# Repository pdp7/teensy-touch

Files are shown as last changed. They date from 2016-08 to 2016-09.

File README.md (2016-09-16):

# Teensy LC cap touch demo
Capactive touch button demo board for Teensy LC with Adafruit 128x64 OLED (SPI)

## OSH Park Shared Project:
* **[Teensy LC cap touch demo](https://oshpark.com/projects/ro7ypcxO)**
   * This is what was ordered and tested
   * File: [teensy-touch.kicad_pcb](https://github.com/pdp7/teensy-touch/blob/5fb2f44a5e37c01898689bddd4195240e6bf3efe/hardware/teensy-touch.kicad_pcb)
   * Commit: [5fb2f44 *connect GND pin for OLED to GND plane*
](https://github.com/pdp7/teensy-touch/commit/5fb2f44a5e37c01898689bddd4195240e6bf3efe)

## Bill of Materials:
* [Monochrome 0.96" 128x64 OLED graphic display](https://www.adafruit.com/product/326)
* [Teensy LC, OSH Park edition](http://store.oshpark.com/products/teensy-lc)

## Videos
* [Short demo](https://www.youtube.com/watch?v=SUqngf3_1D0)
* [Full demo](https://youtu.be/iRWQk5bGx8w)

## Photos
* [Google+ gallery](https://plus.google.com/photos/+DrewFustini/albums/6318204370050037249)
* [images directory](images)

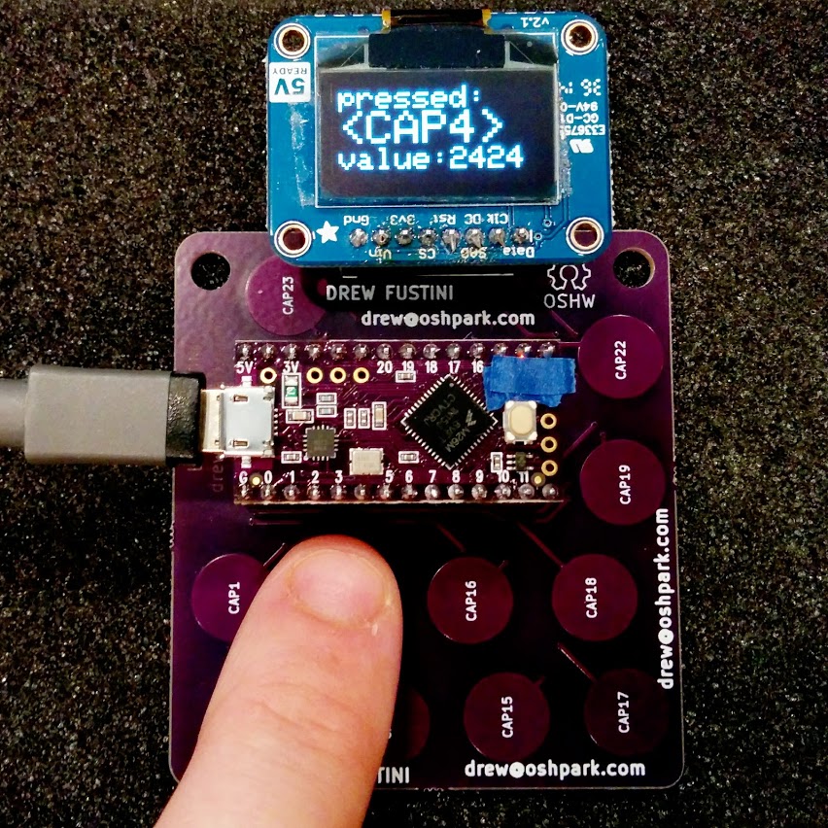
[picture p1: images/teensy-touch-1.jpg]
Photo of teensy-touch board


## License
This project released under the CERN Open Hardware v1.2 License

**Note:** `teensy-touch.ino` contains code based on:

* [Capacitive sensors with the Teensy 3.0](http://njhurst.com/blog/01356576041)
* [SSD1306 display code based on example by Paul Stoffregen](https://www.pjrc.com/teensy/td_libs_SSD1306.html)

## Contact
* Drew Fustini &lt;drew@oshpark.com&gt;

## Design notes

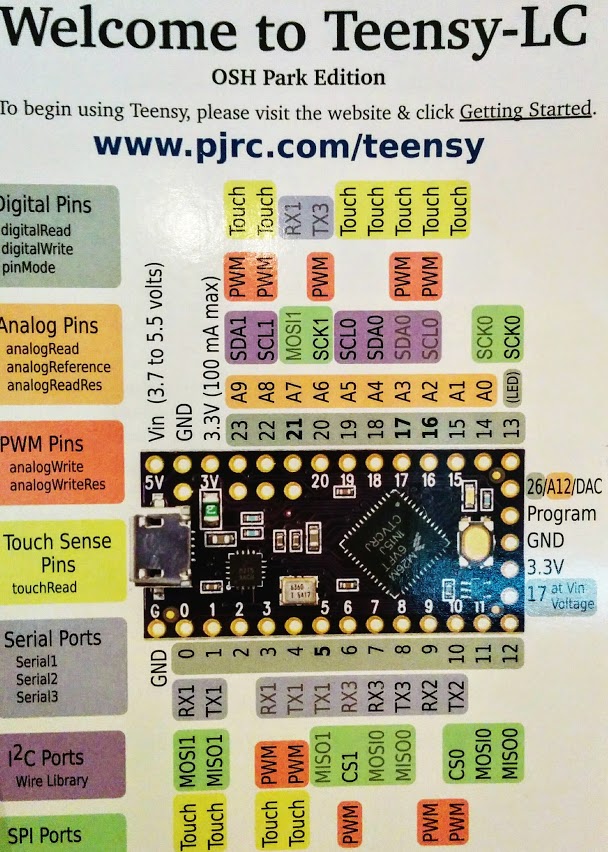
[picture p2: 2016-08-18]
images/teensy-touch-2.jpg

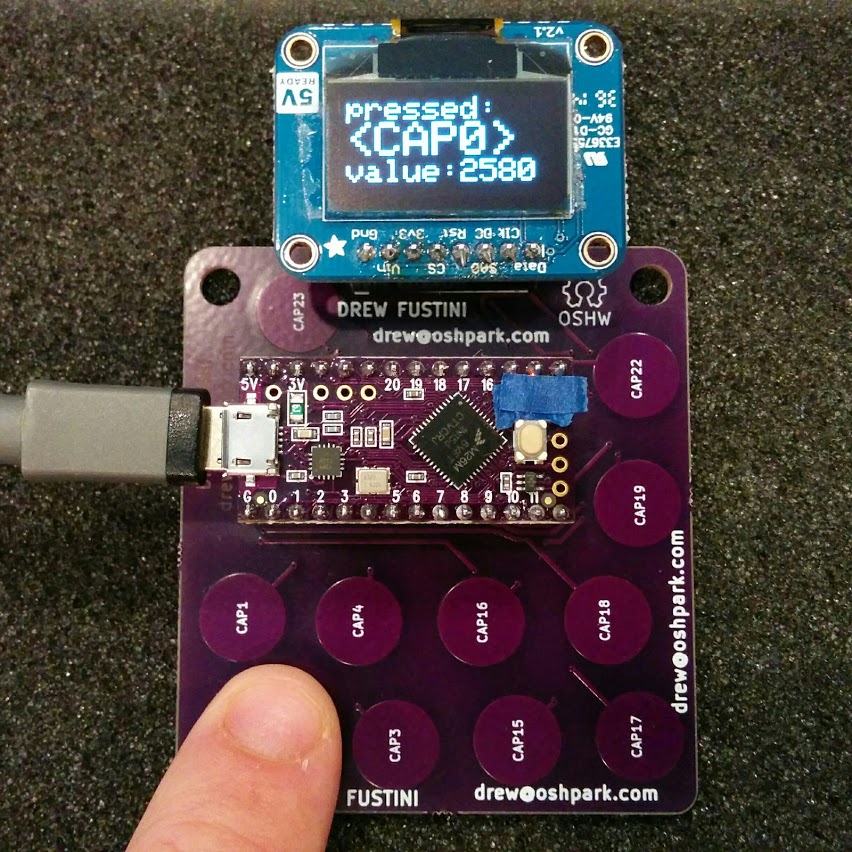
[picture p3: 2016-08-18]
images/teensy-touch-3.jpg

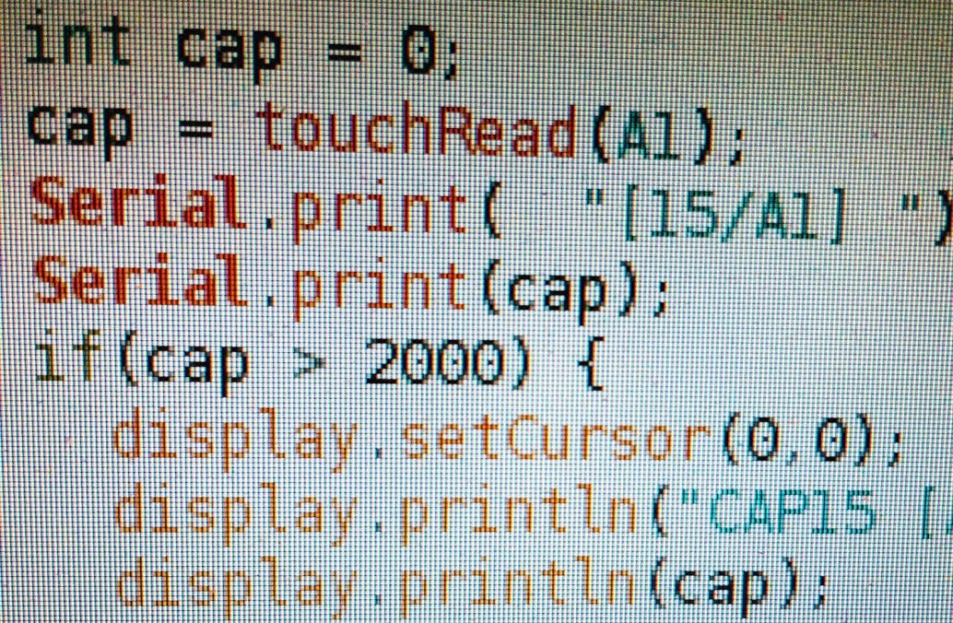
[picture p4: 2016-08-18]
images/teensy-touch-4.jpg

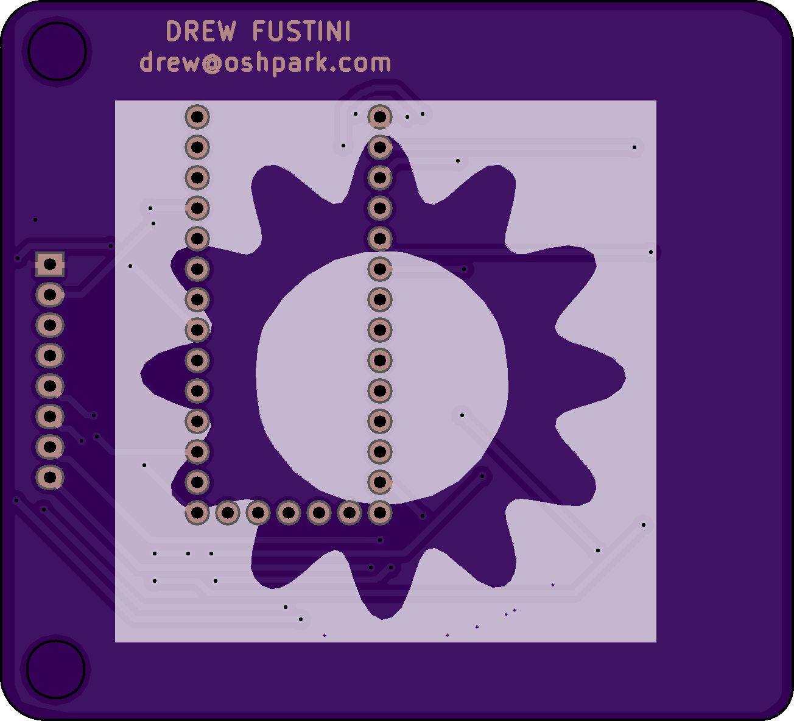
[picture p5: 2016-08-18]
images/back-pcb-preview.png

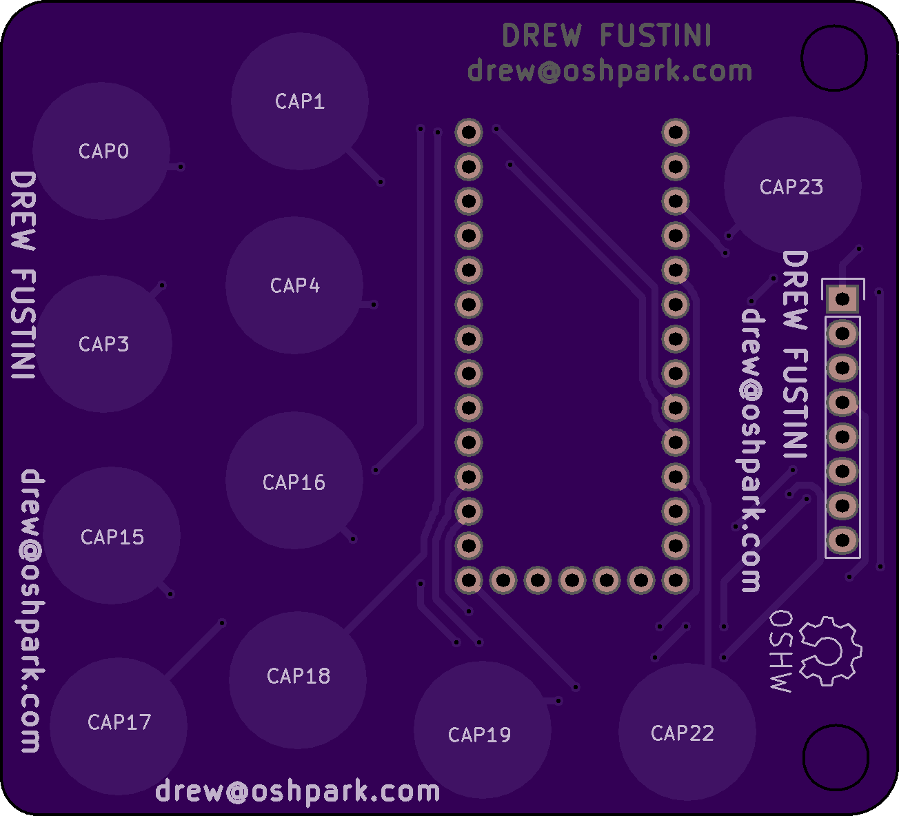
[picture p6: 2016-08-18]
images/front-pcb-preview.png

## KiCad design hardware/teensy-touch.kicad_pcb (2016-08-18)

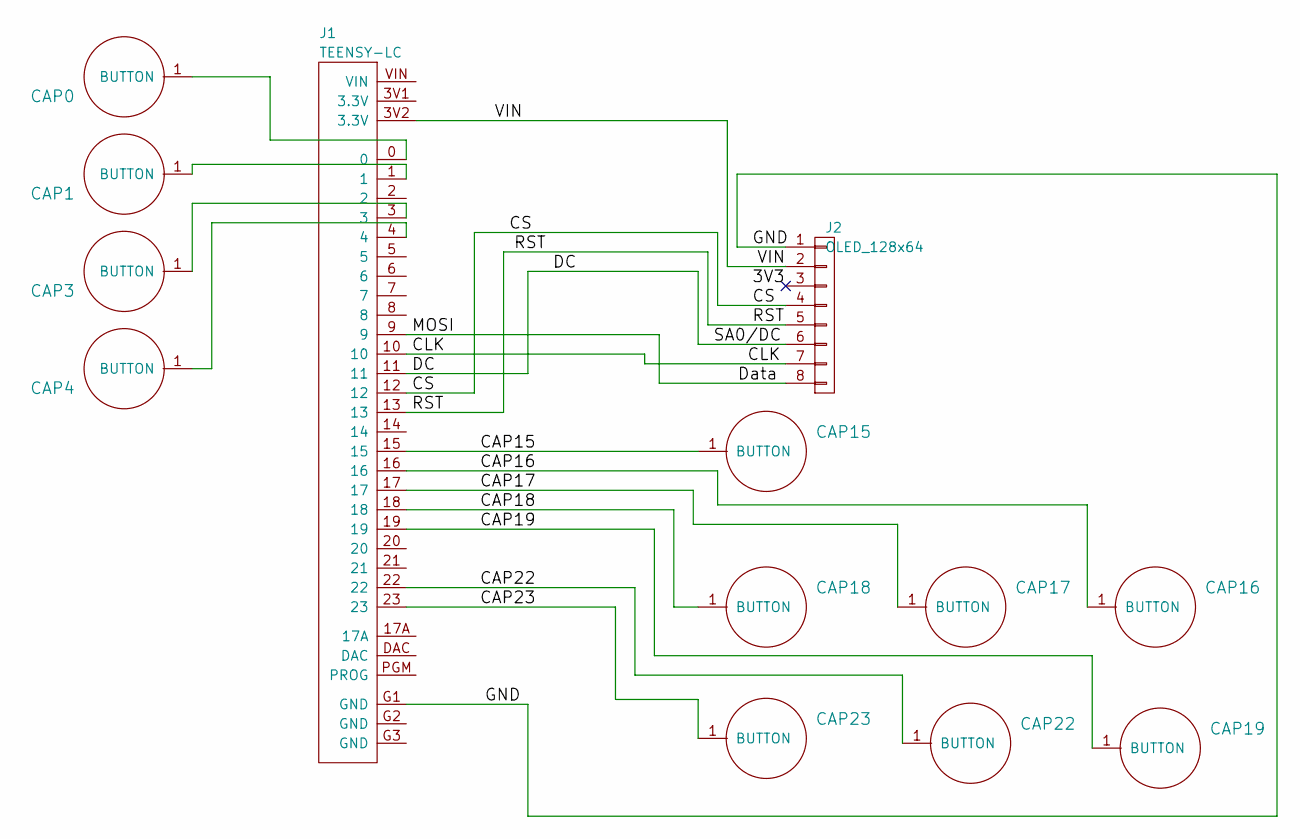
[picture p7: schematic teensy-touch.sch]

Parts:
CAP0, CAP1, CAP3, CAP4, CAP15, CAP16, CAP17, CAP18, CAP19, CAP22, CAP23: CAPSENSE_CIRCLE; CAPSENSE_CIRCLE_D10
J1: TEENSY-LC
J2: OLED_128x64; Pin_Header_Straight_1x08

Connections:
/CAP15: CAP15.1, J1.15
/CAP16: CAP16.1, J1.16
/CAP17: CAP17.1, J1.17
/CAP18: CAP18.1, J1.18
/CAP19: CAP19.1, J1.19
/CAP22: CAP22.1, J1.22
/CAP23: CAP23.1, J1.23
/CLK: J1.10, J2.7
/CS: J1.12, J2.4
/DC: J1.11, J2.6
/Data: J1.9, J2.8
/GND: J1.G1 (GND), J2.1
/RST: J1.13, J2.5
/VIN: J1.3V2 (3.3V), J2.2
unnamed: CAP0.1, J1.0
unnamed: CAP1.1, J1.1
unnamed: CAP3.1, J1.3
unnamed: CAP4.1, J1.4

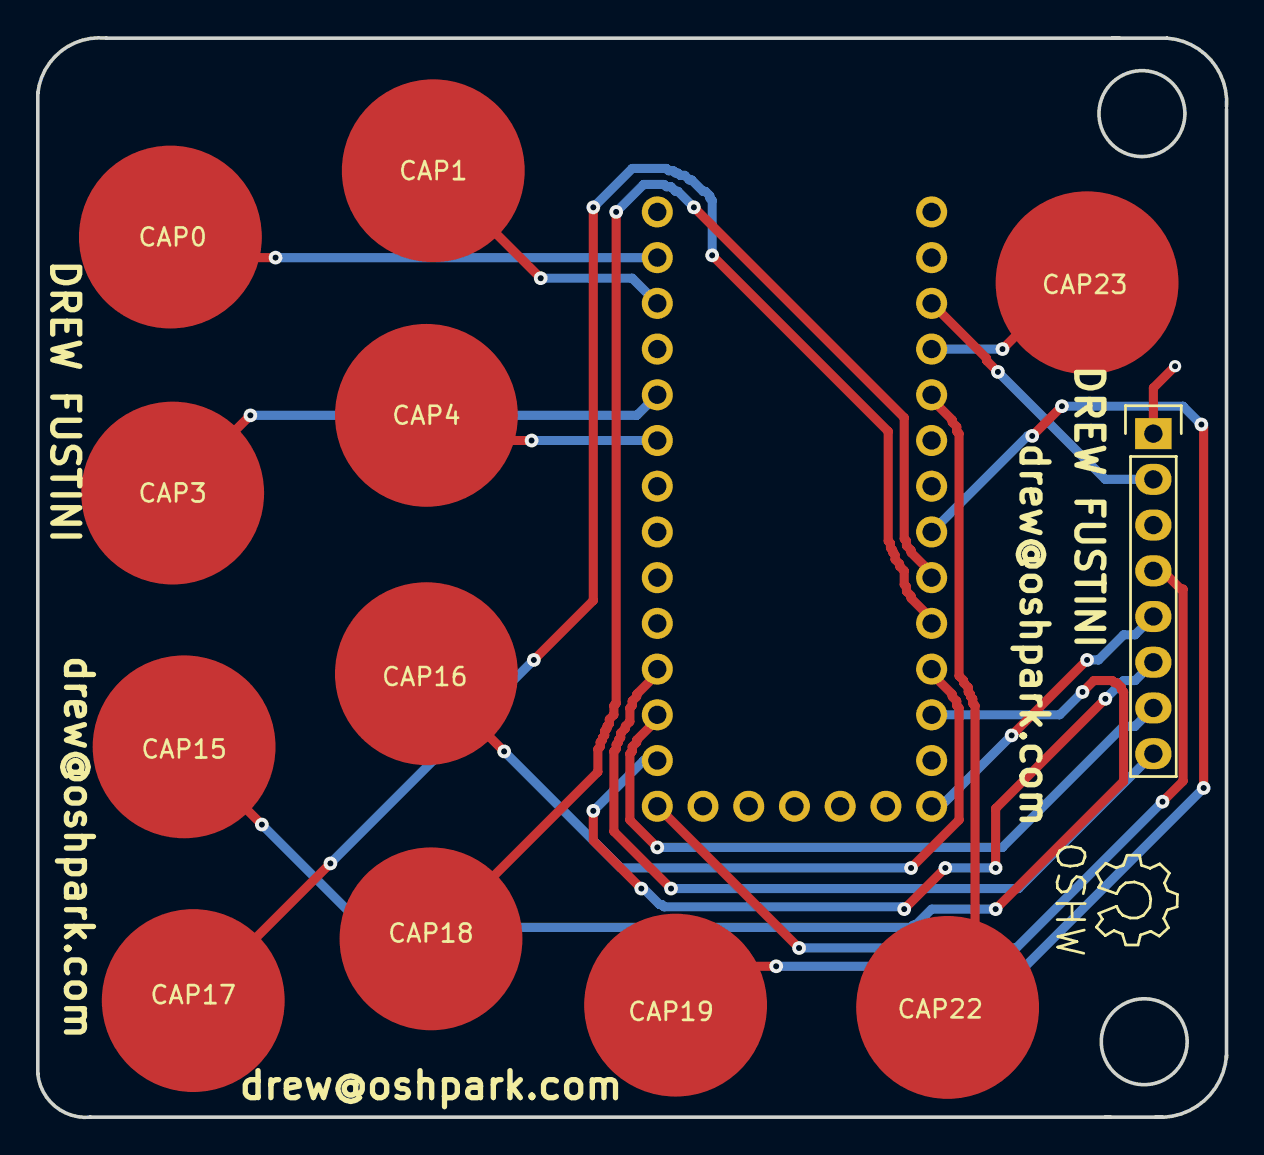
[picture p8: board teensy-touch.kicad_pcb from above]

Board: 2 copper layers, 66.0 x 60.0 mm, 13 parts (0 on the bottom side), 18 nets.

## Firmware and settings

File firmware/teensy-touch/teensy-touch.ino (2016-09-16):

/*
   Test of Cap Touch buttons with Teensy LC

   file: teensy-touch.ino

   gist: https://gist.github.com/pdp7/6503aae568da2d0df85f56d2f1e47c5e

   based on: "Capacitive sensors with the Teensy 3.0"
   http://njhurst.com/blog/01356576041

   SSD1306 display code based on example by Paul Stoffregen:
   https://www.pjrc.com/teensy/td_libs_SSD1306.html
*/

/*
   Adafruit_SSD1306 library changes for upside down Adafruit i2c 128x64 OLED:

   gist: https://gist.github.com/pdp7/687d0db32b30148779b3ff5346c3955e

   path: hardware/teensy/avr/libraries/Adafruit_SSD1306/Adafruit_SSD1306.h
      #define SSD1306_128_64
      //   #define SSD1306_128_32
      //   #define SSD1306_96_16

   forum post: "Re: SSD1306 flip lcd"
      https://forums.adafruit.com/viewtopic.php?f=47&t=25438&sid=c8bd3b6d598bd14259abb4e25cdd43a9

   path: hardware/teensy/avr/libraries/Adafruit_SSD1306/Adafruit_SSD1306.cpp
      //ssd1306_command(SSD1306_SEGREMAP | 0x1);
      ssd1306_command(SSD1306_SEGREMAP);
      //ssd1306_command(SSD1306_COMSCANDEC);
      ssd1306_command(SSD1306_COMSCANINC);

*/

#include <SPI.h>
#include <Wire.h>
#include <Adafruit_GFX.h>
#include <Adafruit_SSD1306.h>

// based on SSD1306 example by Paul Stoffregen
// using software SPI (the default case):
// https://www.pjrc.com/teensy/td_libs_SSD1306.html
#define OLED_MOSI   9
#define OLED_CLK   10
#define OLED_DC    11
#define OLED_CS    12
#define OLED_RESET 13
Adafruit_SSD1306 display(OLED_MOSI, OLED_CLK, OLED_DC, OLED_RESET, OLED_CS);

#define THRESHOLD 1500
#define NBUTTON 11
#define NULL_VALUE -1

void setup() {
  display.begin(SSD1306_SWITCHCAPVCC, 0x3C);  // initialize with the I2C addr 0x3C (for the 128x32)
  display.clearDisplay();
  display.setCursor(0, 0);
  display.setTextSize(2);
  display.setTextColor(WHITE);
  display.println("Teensy LC cap touch test");
  display.display();
  delay(1000);
  display.clearDisplay();
  display.display();
}

// the loop() methor runs over and over again,
// as long as the board has power

void loop() {
  /*
    int a = touchRead(A9);
    int b = touchRead(A8);
    Serial.println((a - b) * 1000 / (a + b));
    delay(100);
  */
  int reading = 0;
  int val = 0;
  int disp_sample = NULL_VALUE;
  String label;

  int sample[NBUTTON];
  String desc[NBUTTON] = { "CAP15", "CAP16", "CAP17", "CAP18",
                           "CAP19", "CAP22", "CAP23", "CAP0",
                           "CAP1",  "CAP3",  "CAP4"
                         };
  int pin[NBUTTON] =     {  A1,      A2,      A3,      A4,
                            A5,      A8,      A9,       0,
                            1,       3,       4
                         };

  // TODO: support simultaneous button presses
  for (int i = 0; i < NBUTTON; i++) {

    sample[i] = touchRead(pin[i]);

    /*
        NOTE: only one pressed button
        will "win" for each iteration
        of loop(). Thus "multi-touch"
        is not supported.
    */
    if (sample[i] > THRESHOLD) {
      disp_sample = i;
    }

    Serial.print(i);
    Serial.print("\t");
    Serial.print(sample[i]);
    Serial.print("\t");
    Serial.print(pin[i] );
    Serial.print("\t");
    Serial.print(desc[i] );
    Serial.print("\t");
    Serial.print( disp_sample );
    Serial.println();
  }

  display.clearDisplay();
  display.setCursor(0, 0);
  display.setTextColor(WHITE);
  display.setTextSize(2);

  if (disp_sample > -1) {
    display.println("touched:");

    display.setTextSize(3);
    display.print("<");
    display.print(desc[disp_sample]);
    display.println(">");

    display.setTextSize(2);
    display.print("value:");
    display.println(sample[disp_sample]);
  } else {
    display.println("Touch any button");
  }
  display.display();
  delay(100);

}

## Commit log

2016-08-11 Add KiCad schematic and board layout
    Originally from git repo:
    https://github.com/pdp7/teensy-big-oled
    [teensy-touch.kicad_pcb, teensy-touch.sch]
2016-08-11 add teensy touch sketch from gist
    Original gist:
    https://gist.github.com/pdp7/6503aae568da2d0df85f56d2f1e47c5e
2016-08-11 display each cap touch button
2016-08-11 refactor display of button press
2016-08-11 improve button press handling
2016-08-18 connect GND pin for OLED to GND plane
    [teensy-touch.kicad_pcb]
2016-08-18 add PCB preview from OSH Park
